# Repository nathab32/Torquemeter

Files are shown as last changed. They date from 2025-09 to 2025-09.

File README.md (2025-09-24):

# Torquemeter

## About

Static torquemeter designed for rubber powered flying devices (planes, helicopters). The design uses a lever arm, load cell, instrumentation amplifier, and 24-bit ADC. The code uses my own button, NAU7802, and moving average libraries. The control of the display is handled by Adafruit's SSD1306 and GFX libraries, while a low pass filter is copied from curiores's ArduinoTutorials repository (found [here](https://github.com/curiores/ArduinoTutorials/blob/main/BasicFilters/ArduinoImplementations/LowPass/LowPass2.0/LowPass2.0.ino)).

### Features

- Maximum torque of 230gf-cm, or about 3.2 oz-in.
- Easy to switch to different units (oz-in, gf-cm, in-lb, mN-m)
- Tare feature to compare torques
- Program can be easily calibrated and reflashed
- Overload warning
- Stopwatch to manage winding of rubber bands
- More features planned in the future (Battery power, serial output, logging to spreadsheet, 3D printed enclosure)

## Parts

- Arduino Nano w/ USB-Type C (or Uno if not inside enclosure)
- 100g load cell (Mine is an unspecified one from Amazon, but is very similar to the [TAL221](https://cdn.sparkfun.com/assets/9/9/a/f/3/TAL221.pdf))
- EL8172 instrumentation amplifier
- NAU7802 ADC
- I2C 128x64 display
- 3x SPST momentary push buttons
- Resistors, capacitors (see schematic for specifics)
- 7mm OD, 3mm ID, 3mm thick ball bearing
- Piano wire for making hook
- 100g calibration weight

## Schematic

I haven't made the PCB yet, but once that is done, I will upload the full KiCAD files to the repository.

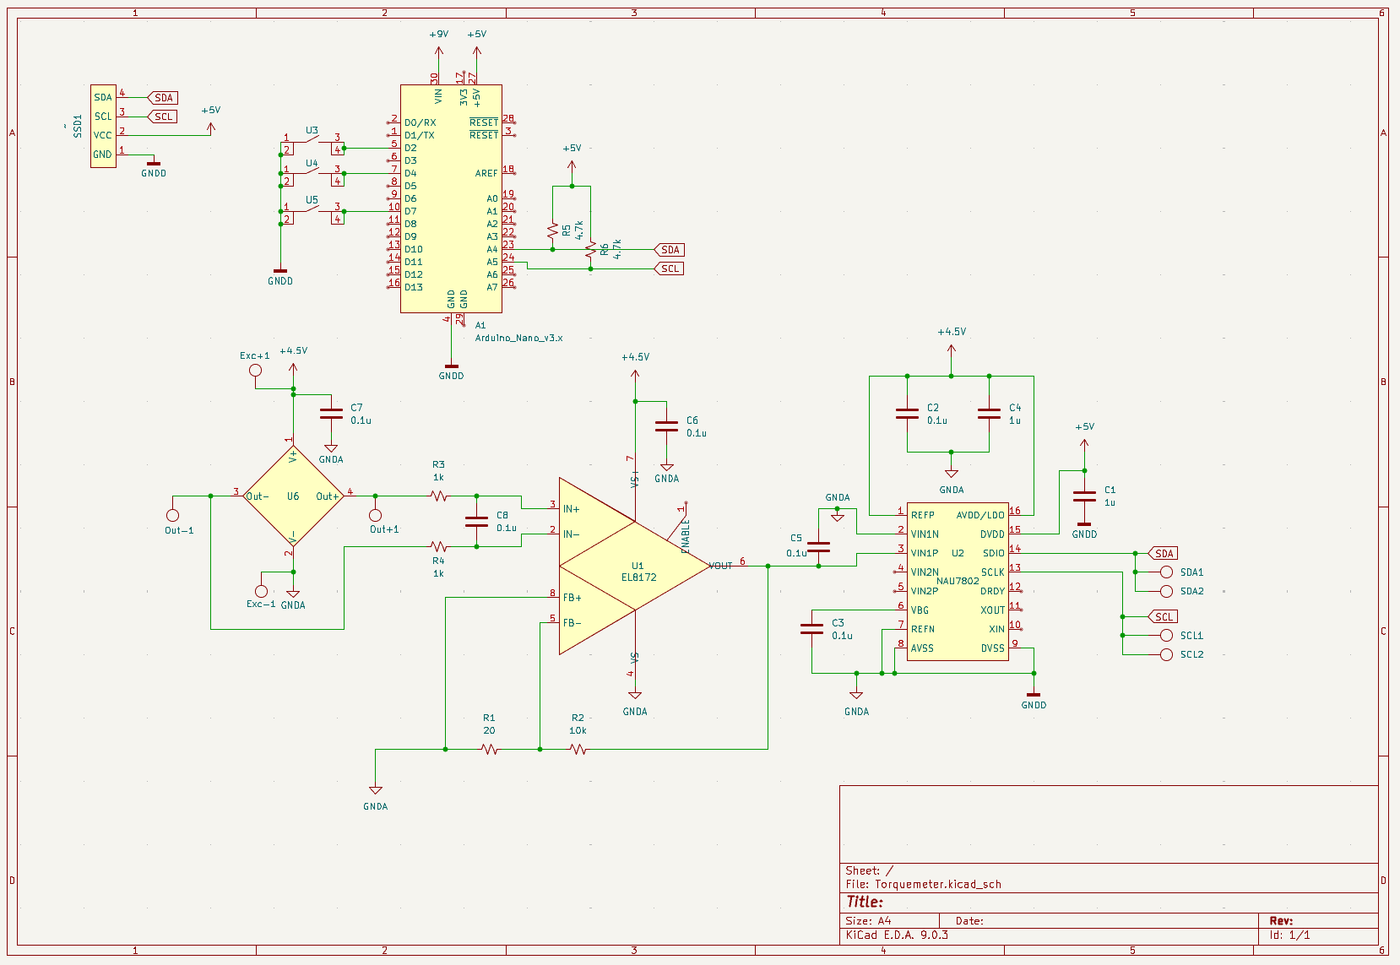
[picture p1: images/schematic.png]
Schematic image


## 3D Prints

The enclosure has not been tested, but a functional version can be made using a simple test bench for the load cell and lever arm. Print `Calibration.step`, `LeverArm.step`, and `LoadCellTester.step` inside the `3DFiles` folder.

1. Secure the load cell using 2x M3x12 screws, and 2x M3 nuts on the bottom. My load cell has threads on the wire side, which make the threads on the nuts misaligned and the assembly is loose. You may consider drilling out the threads if you have them so the load cell is more secure, but it works well enough without drilling them out.
2. Push the lever arm into the ball bearing.
3. Bend the hook without the right angle as shown in `images/testBench.jpg`, and stick it through the lever arm/ball bearing assembly.
4. Bend the right angle in the piano wire so that the angle lies in one of the cutouts when the hook is facing upwards.
5. (Optional) Glue the hook in the front and back, being careful to not get glue in the bearing.

## Code

Inside `src` is the `main.cpp` file that will run on the Arduino. Upload this using PlatformIO in VSCode to start calibration.

### Calibration

1. With the calibration disk placed on the load cell, turn on the Arduino.
2. If `debug = true` inside of main, there should be 6 values being printed out on the screen. Tared voltage and mass should be close to 0.
3. Place the 100g calibration weight onto the calibration disk, and start monitoring the `calValue` line.
4. Take an estimate of the `calValue`, then set `calValue` in `main.cpp` to the estimate.
5. Take off the calibration weight and reset the Arduino.
6. Set the calibration weight down again, and the mass should now read close to 100g.

### Overload

1. Without changing the setup from the last calibration step (calibration disk tared, 100g on the platform), monitor the `Raw Voltage` value.
2. Add a tiny bit of extra weight (w/ paper clips, finger, etc.), until the mass reaches your desired overload value. Keep in mind the safe overload of the TAL221 is 150g (I chose 105g).
3. When the mass reaches your chosen overload value, take note of the `Raw Voltage` value.
4. In `main.cpp`, set `overloadVoltage` to the voltage from the previous step.
5. The torque should now say `OVERLOAD` if the voltage (tared or untared) is detected to be over the set value.

### Buttons

The three buttons' functionality is summarized below. The pin, debounce time, and hold time can be customized by modifying the constructors in `main.cpp`.

| Button | Pin | Press | Hold |
|---|-----|---|---|
| 1 | 2 | switch units | N/A |
| 2 | 4 | tare | switch debug on/off |
| 3 | 7 | start timer  | N/A |

## Data Logging

Inside of the `data` folder, you'll find a python file that enables logging of the data using the serial port. However, before this is possible, the serial port and baud rate may need to be changed.

- Change `PORT` to the port you uploaded the Torquemeter program to. It may be helpful to look in the device manager, or run `pio device list` in the PlatformIO CLI.
- `BAUD` should be changed to whatever serial speed you're running at. The default speed set in `main.cpp` is 9600.

After those values have been changed, you may proceed with data logging.

1. Plug the torquemeter into your computer's USB port, and ensure the serial port in the python file matches the Arduino's serial port.
2. Run the python file. The Torquemeter's serial output should be printed in the command prompt.
3. Collect your data. The timer time is also recorded if necessary. The current unit displayed on the torquemeter is not important; at the end of logging, all units will be recorded.
4. End data collection and save the data by holding button 3 of the torquemeter until the screen flashes with the text "Serial off". The data will be saved inside of the data folder with a time stamp of when the data was recorded.

To collect data again, rerun the python file. Keep in mind this resets the Torquemeter, so any tare or timer that is going on will be reset. To cancel collection and prevent data from being saved, do `Ctrl+C` when inside of the command line used to run the python file.

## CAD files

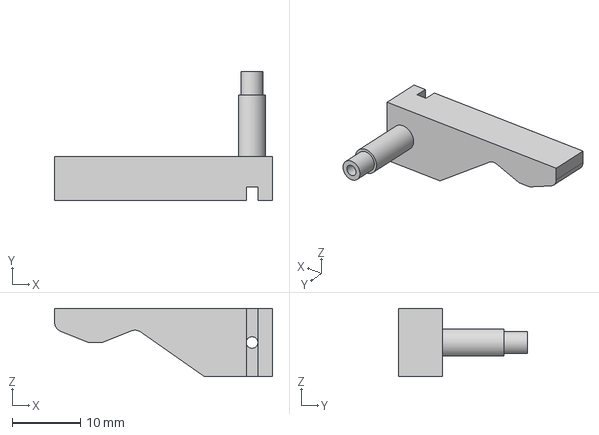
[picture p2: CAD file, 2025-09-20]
3DFiles/LeverArm.step
32.0 x 19.0 x 10.0 mm

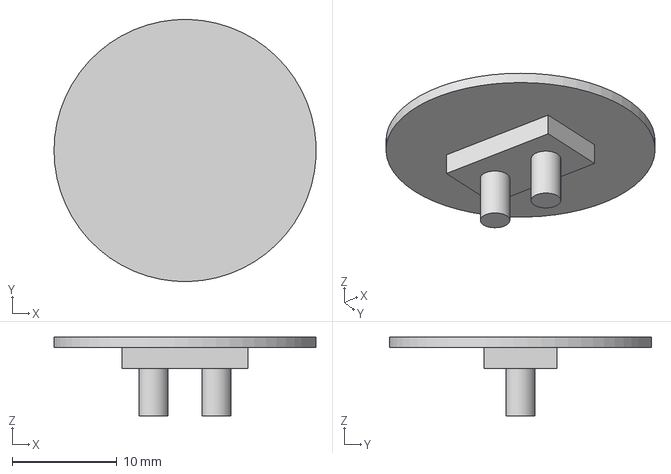
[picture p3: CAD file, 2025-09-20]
3DFiles/Calibration.step
25.0 x 25.0 x 7.50 mm

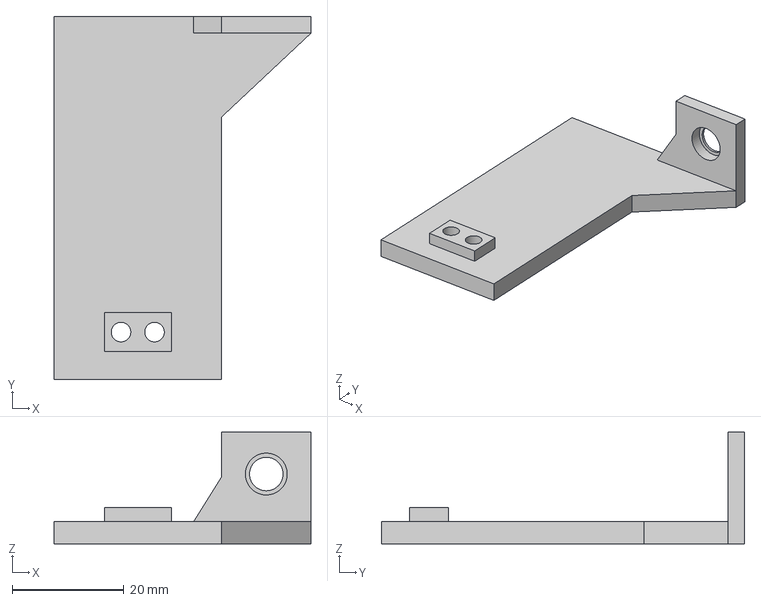
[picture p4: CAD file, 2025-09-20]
3DFiles/LoadCellTester.step
46.0 x 65.0 x 20.0 mm

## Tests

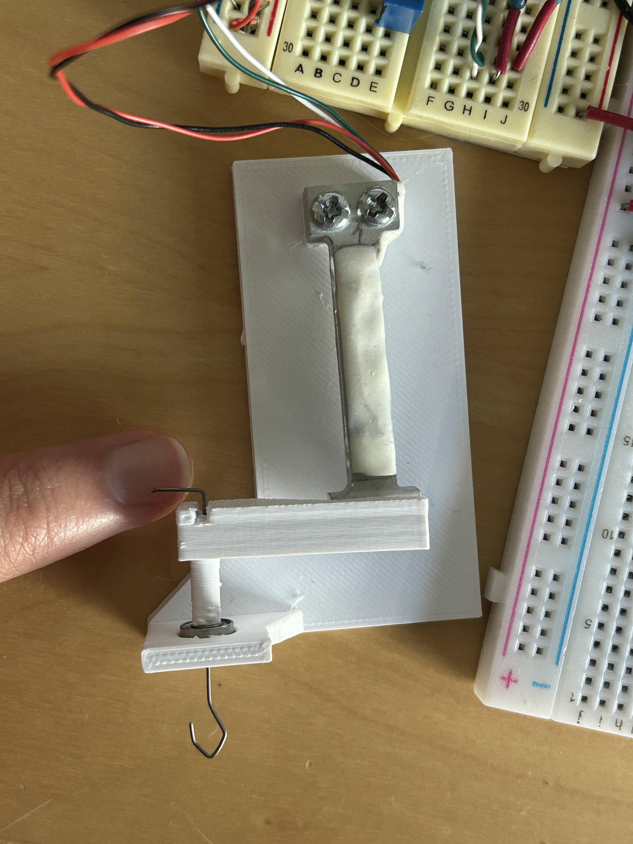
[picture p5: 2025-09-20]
images/testBench.jpg

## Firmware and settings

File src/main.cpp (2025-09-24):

#include <Arduino.h>
#include <Adafruit_SSD1306.h>
#include <NAU7802.h>
#include <Button.h>
#include <MovingAverage.h>
#include "LowPass2.0.h"

// user-defined variables
bool debug = true;
float calValue = 54.4;
float armLengthCM = 2.3; //stock arm is 2.3cm
float overloadVoltage = 2.15; //use debug to find
int serialSpeed = 9600;

// variables
Adafruit_SSD1306 display(128, 64, &Wire, -1);
NAU7802 adc;

Button button1(2, 50, 1500);// button 1 switches units
Button button2(4, 50, 1500);// button 2 zeroes the scale and calibrates on hold
Button button3(7, 50, 1500);// button 3 turns on a timer and enables serial output on hold

enum TorqueUnit
{
  OZ_IN,
  GF_CM,
  IN_LB,
  MN_M,
  UNIT_COUNT
};
TorqueUnit unit = OZ_IN;
float torqueFactor = 0.01388738 * armLengthCM;
int decimals = 2;
String suffix = "ozin";

bool timerOn = false;
unsigned long startTime;

bool serialOn = true;

const int avgLength = 10;
LowPass<2> filter(1.0, 9.3, true);
MovingAverage<uint_fast32_t> avg(avgLength);
// MovingAverage<uint_fast32_t> avg1(5);
float tareReading;

// functions

void onePressCallback(){
  unit = static_cast<TorqueUnit>((unit+1) % UNIT_COUNT);
  switch (unit)
  {
  case OZ_IN:
    torqueFactor = 0.01388738 * armLengthCM;
    decimals = 2;
    suffix = F("ozin");
    break;
  case GF_CM:
    torqueFactor = armLengthCM;
    decimals = 2;
    suffix = F("gfcm");
    break;
  case IN_LB:
    torqueFactor = 0.0008679617 * armLengthCM;
    decimals = 5;
    suffix = F("inlb");
    break;
  case MN_M:
    torqueFactor = 0.0980665 * armLengthCM;
    decimals = 3;
    suffix = F("mNm");
    break;
  case UNIT_COUNT:
    break;
  }
}

void twoPressCallback(){
  while (!adc.getDataReady()) delay(10);
  long adcVal = adc.read();
  float lpFilter = filter.filt(adcVal);
  tareReading = avg.update(lpFilter) * 4.5 / pow(2, 24);
}

void threePressCallback(){
  timerOn = !timerOn;
  startTime = millis();
}

void oneHoldCallback(){

}

void twoHoldCallback(){
  debug = !debug;
}

void threeHoldCallback(){
  serialOn = !serialOn;

  display.clearDisplay();
  display.setCursor(0, 0);
  display.setTextSize(2);
  if (serialOn) {
    display.println(F("Serial On"));
  } else {
    display.println(F("Serial Off"));
    Serial.println(F("exit"));
  }
  display.display();
  delay(1000);
}


void displaySetup() {
  if (display.begin(SSD1306_SWITCHCAPVCC, 0x3C)) {
    Serial.println(F("SSD1306 initialized successfully."));
  } else {
    Serial.println(F("SSD1306 initialization failed."));
  }
  display.clearDisplay();
  display.fillScreen(SSD1306_WHITE);
  display.setTextColor(SSD1306_BLACK);
  display.setTextSize(1);
  display.setTextWrap(true);
  display.setCursor(31, 24);
  display.print(F("Torquemeter"));
  display.setCursor(24, 32);
  display.print(F("by Nathan Chiu"));
  display.setTextColor(SSD1306_WHITE);
  display.display();
}

void setup() {
  Serial.begin(serialSpeed);
  Serial.println(F("Serial started"));
  displaySetup();

  //ADC setup
  {
    if(adc.begin() == true) {
      Serial.println(F("NAU7802 initialized successfully."));
    } else {
      Serial.println(F("NAU7802 initialization failed."));
    }
    adc.standby(false);
    adc.setAnalogSupply(NAU7802_SUPPLY_4V5);
    adc.setChannel(NAU7802_CHANNEL_1);
    adc.setConversionRate(NAU7802_CONVERSIONRATE_80);
    adc.setLdoMode(NAU7802_LDOMODE_1);
    adc.pgaBypass(true);
    adc.calibrate(NAU7802_CALIBRATE_INTERNAL_OFFSET);
  }

  //button setup
  {
    button1.pressFunction(onePressCallback);
    button2.pressFunction(twoPressCallback);
    button3.pressFunction(threePressCallback);
    button1.holdFunction(oneHoldCallback);
    button2.holdFunction(twoHoldCallback);
    button3.holdFunction(threeHoldCallback);
  }

  //tare / moving avg setup
  {
    for (int i = 0; i < avgLength; i++) {
      while (!adc.getDataReady()) delay(10);
      avg.update(adc.read());
      // Serial.println(val);
      delay(50);

    }
    // Serial.println(sum);
    tareReading = avg.getAverage() * 4.5 / pow(2, 24);
    // Serial.print("Tare value:");
    // Serial.println(tareReading);
  }
}


void loop() {
  while (!adc.getDataReady()) delay(10);
  long adcVal = adc.read();
  float lpFilter = filter.filt(adcVal);

  //filtering testing
{  
  // float voltage = adcVal * 4.5 / pow(2, 24) - tareReading;
  // float voltageFiltered = lpFilter * 4.5 / pow(2, 24) - tareReading;
  // float voltageAveraged = avg.update(adcVal) * 4.5 / pow(2, 24) - tareReading;
  // float voltageCombined = avg1.update(lpFilter) * 4.5 / pow(2, 24) - tareReading;

  // float mass = (voltage * .995) * 100/2.7;
  // float massFiltered = (voltageFiltered * .995) * 100 / 2.7;
  // float massAveraged = (voltageAveraged * .995) * 100 / 2.7;
  // float massCombined = (voltageCombined * .995) * 100 / 2.7;

  // Serial.print(F(">Voltage:"));
  // Serial.print(voltage,4);
  // Serial.print(F(",voltageFiltered:"));
  // Serial.print(voltageFiltered, 4);
  // Serial.print(F(",voltageAveraged:"));
  // Serial.print(voltageAveraged, 4);
  // Serial.print(F(",voltageCombined:"));
  // Serial.print(voltageCombined, 4);

  // Serial.print(F(",zero:0"));

  // Serial.print(F(",massFiltered:"));
  // Serial.print(massFiltered, 4);
  // Serial.print(F(",massAveraged:"));
  // Serial.print(massAveraged, 4);
  // Serial.print(F(",massCombined:"));
  // Serial.print(massCombined, 4);
  // Serial.print(F(",mass:"));
  // Serial.println(mass,4);
  }
  
  float voltage = avg.update(lpFilter) * 4.5 / pow(2, 24) - tareReading;
  bool overload = (voltage + tareReading) > overloadVoltage;
  float mass = voltage * calValue;
  

  button1.handle();
  button2.handle();
  button3.handle();

  display.clearDisplay();
  display.setCursor(0, 0);
  display.setTextSize(1);

  float torque = mass * torqueFactor;
  //print to screen
  if (debug)
  {  
    display.print(F("Raw Voltage: "));
    display.println(voltage+tareReading, 3);

    display.print(F("Tared voltage: "));
    display.println(voltage, 3);

    display.print(F("calValue: "));
    display.println(100 / voltage, 3);

    display.print(F("Mass: "));
    display.println(mass, 2);

    display.print(F("Torque: "));
    if (overload) display.println(F("OVERLOAD"));
    else {
      display.print(torque, decimals);
      display.println(" " + suffix);
    }

    display.print(F("Timer: "));
    
  }
  else
  {
    display.setTextSize(2);
    display.println(F("Torque: "));
    if (overload) display.println(F("OVERLOAD\n"));
    else {
      display.println(torque, decimals);
      display.println(suffix);
    }
  }

  if (timerOn) display.print((millis() - startTime) / 1000.0, 2);
  else display.print(F("0.00"));
  display.println(F("s"));
  display.display();

  //print to serial
  if (serialOn) {
    Serial.print(F("<"));

    //time
    Serial.print(millis());
    Serial.print(F(","));

    //stopwatch time
    if (timerOn) Serial.print((millis() - startTime));
    else Serial.print(F("0"));
    Serial.print(F(","));

    //torque
    Serial.print(torque, decimals);
    Serial.print(F(","));

    //units
    Serial.print(suffix);
    Serial.println(F(">"));
  }
  
}

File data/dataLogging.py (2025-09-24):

import serial
import pandas as pd
import numpy as np
import time
import datetime

PORT = "COM7"
BAUD = 9600
SERIAL_TIMEOUT = 1 # timeout for serial port data
DATA_TIMEOUT = 5 # time until program ends if no data detected

ser = serial.Serial(PORT, BAUD, timeout=SERIAL_TIMEOUT)
time.sleep(2) # wait for Arduino reset

programTime = []
relativeTime = []
torque = []
unit = []

try:
    last_received_time = time.time()

    while True:
        line = ser.readline()
        if not line:
            if time.time() - last_received_time > DATA_TIMEOUT:
                print('Data timeout activated')
                break
            continue

        last_received_time = time.time()

        text = line.decode("utf-8", "replace").strip()
        if text.startswith('<') and text.endswith('>'):
            text = text.lstrip('<').rstrip('>').split(',')

            programTime.append(int(text[0]))
            relativeTime.append(int(text[1]))
            torque.append(float(text[2]))
            unit.append(text[3])

        elif 'exit' in text:
            print('Exit detected')
            break

        print(text)
except KeyboardInterrupt:
    pass
finally:
    ser.close()
    print('Serial closed')

    programTimeNP = np.array(programTime, dtype=np.float32) / 1000
    relativeTimeNP = np.array(relativeTime, dtype=np.float32) / 1000
    torqueNP = np.array(torque, dtype=np.float32)
    unitNP = np.array(unit)

    torqueOZ_IN = np.empty(len(torqueNP))
    torqueGF_CM = np.empty(len(torqueNP))
    torqueIN_LB = np.empty(len(torqueNP))
    torqueMN_M  = np.empty(len(torqueNP))

    for i in range(len(torqueNP)):
        if unit[i] in 'ozin':
            torqueOZ_IN[i] = torqueNP[i]
            torqueGF_CM[i] = torqueOZ_IN[i] * 72.007790632
            torqueIN_LB[i] = torqueOZ_IN[i] * 0.0624999993
            torqueMN_M[i] = torqueOZ_IN[i] * 7.061552

        elif unit[i] in 'gfcm':
            torqueGF_CM[i] = torqueNP[i]
            torqueOZ_IN[i] = torqueGF_CM[i] * 0.0138873862
            torqueIN_LB[i] = torqueGF_CM[i] * 0.0008679616
            torqueMN_M[i] = torqueGF_CM[i] * 0.0980665

        elif unit[i] in 'inlb':
            torqueIN_LB[i] = torqueNP[i]
            torqueOZ_IN[i] = torqueIN_LB[i] * 16.000000189
            torqueGF_CM[i] = torqueIN_LB[i] * 1152.1246637
            torqueMN_M[i] = torqueIN_LB[i] * 112.98483333

        elif unit[i] in 'mNm':
            torqueMN_M[i] = torqueNP[i]
            torqueOZ_IN[i] = torqueMN_M[i] * 0.1416119289
            torqueGF_CM[i] = torqueMN_M[i] * 10.19716213
            torqueIN_LB[i] = torqueMN_M[i] * 0.0088507455
        

    df = pd.DataFrame({
        'programTime (s)' : programTimeNP, 
        'relativeTime (s)' : relativeTimeNP, 
        'torque (ozin)' : torqueOZ_IN, 
        'torque (gfcm)' : torqueGF_CM, 
        'torque (inlb)' : torqueIN_LB, 
        'torque (mNm)' : torqueMN_M
        })
    
    print(df)

    timestamp = datetime.datetime.now().strftime("%Y-%m-%d_%H-%M-%S")

    writer = pd.ExcelWriter(f"data/excel/torque_{timestamp}.xlsx", engine='xlsxwriter')
    df.to_excel(writer, sheet_name='Sheet1', index=False)
    workbook = writer.book
    worksheet = writer.sheets['Sheet1']
    chart = workbook.add_chart({'type':'scatter'})
    chart.add_series({
        'categories': ['Sheet1', 0, 0, len(programTimeNP)-1, 0],
        'values': ['Sheet1', 1, 2, len(torqueOZ_IN)-1,2],
        'marker': {
            'type': 'diamond', 
            'size': 2,
            'border': {'color': 'black'},
            'fill': {'color': 'black'}
        },
        'name': 'torque (ozin)'
    })
    chart.add_series({
        'categories': ['Sheet1', 0, 0, len(programTimeNP)-1, 0],
        'values': ['Sheet1', 1, 3, len(torqueGF_CM)-1,3],
        'marker': {
            'type': 'diamond', 
            'size': 2,
            'border': {'color': 'red'},
            'fill': {'color': 'red'}
        },
        'name': 'torque (gfcm)'
    })
    chart.add_series({
        'categories': ['Sheet1', 0, 0, len(programTimeNP)-1, 0],
        'values': ['Sheet1', 1, 4, len(torqueIN_LB)-1,4],
        'marker': {
            'type': 'diamond', 
            'size': 2,
            'border': {'color': 'blue'},
            'fill': {'color': 'blue'}
        },
        'name': 'torque (inlb)'
    })
    chart.add_series({
        'categories': ['Sheet1', 0, 0, len(programTimeNP)-1, 0],
        'values': ['Sheet1', 1, 5, len(torqueMN_M)-1,5],
        'marker': {
            'type': 'diamond', 
            'size': 2,
            'border': {'color': 'green'},
            'fill': {'color': 'green'}
        },
        'name': 'torque (mNm)'
    })
    chart.set_x_axis({'name': 'Program Time (s)'})
    chart.set_y_axis({'name': 'Torque'})
    chart.set_size({'x_scale': 1.5, 'y_scale': 2})
    worksheet.insert_chart('H2', chart)
    writer.close()

    df.to_csv(f"data/csv/torque_{timestamp}.csv", index=False)
    print(f'df written to data folder as torque_{timestamp}')

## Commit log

2025-08-08 Add Button header and source files
2025-08-12 add constructor to button
2025-08-15 Implement control for push buttons with hold function
2025-08-15 Move Button files to lib folder
2025-08-29 Add Low Pass filter from curiores
2025-09-19 Remove Button and NAU7802 library files and switch to libraries I uploaded to PlatformIO
2025-09-19 Add basic working code for torquemeter, giving multiple units for torque
2025-09-20 Add tare function, fix torquefactor bug, and simplify voltage to mass conversion
    [main.cpp]
2025-09-20 Add timer
2025-09-20 Add user defined variables, overload warning, debug mode, and start of calibration mode
2025-09-20 Overload warning when tared as well, remove calibration mode, and cleaned up formatting of debug mode. Last commit before first ship on SOM
2025-09-20 Add schematic
2025-09-20 Add schematic image
2025-09-20 Remove schematic pdf
2025-09-20 Add test bench STEP files
    [Calibration.step, LeverArm.step, LoadCellTester.step]
2025-09-20 rename schematic image
2025-09-20 Add calibration to debug mode
2025-09-20 Fix schematic image, make button table clearer
2025-09-20 Update button library version
2025-09-23 fix wrong starting torque factor
    [main.cpp]
2025-09-23 Add dataLogging file and logging folders
    [torque_2025-09-22_22-56-11.csv, torque_2025-09-22_22-56-11.xlsx]
2025-09-24 Fix initial decimals and add custom serial speed
    [main.cpp]
2025-09-24 New format for data
    [torque_2025-09-23_21-21-51.csv]
2025-09-24 Remove old data format
    [torque_2025-09-22_22-56-11.csv, torque_2025-09-22_22-56-11.xlsx]
2025-09-24 Include all supported units, and adds graph to xlsx file with all torques plotted against time
